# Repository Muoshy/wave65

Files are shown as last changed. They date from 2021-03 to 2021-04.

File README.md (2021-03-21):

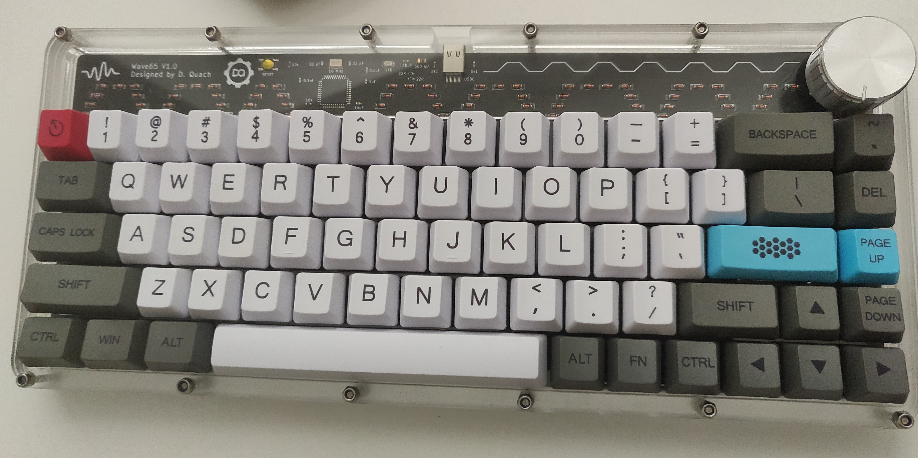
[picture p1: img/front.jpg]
top


# wave65
discipline65 inspired keyboard

  - QMK firmware
  - Acrylic sandwich case
  - Encoder support
  - VIA-configurable
  
## Schematic
Standard ATMega32u4 setup with Wurth/Amphenol USB-C connector
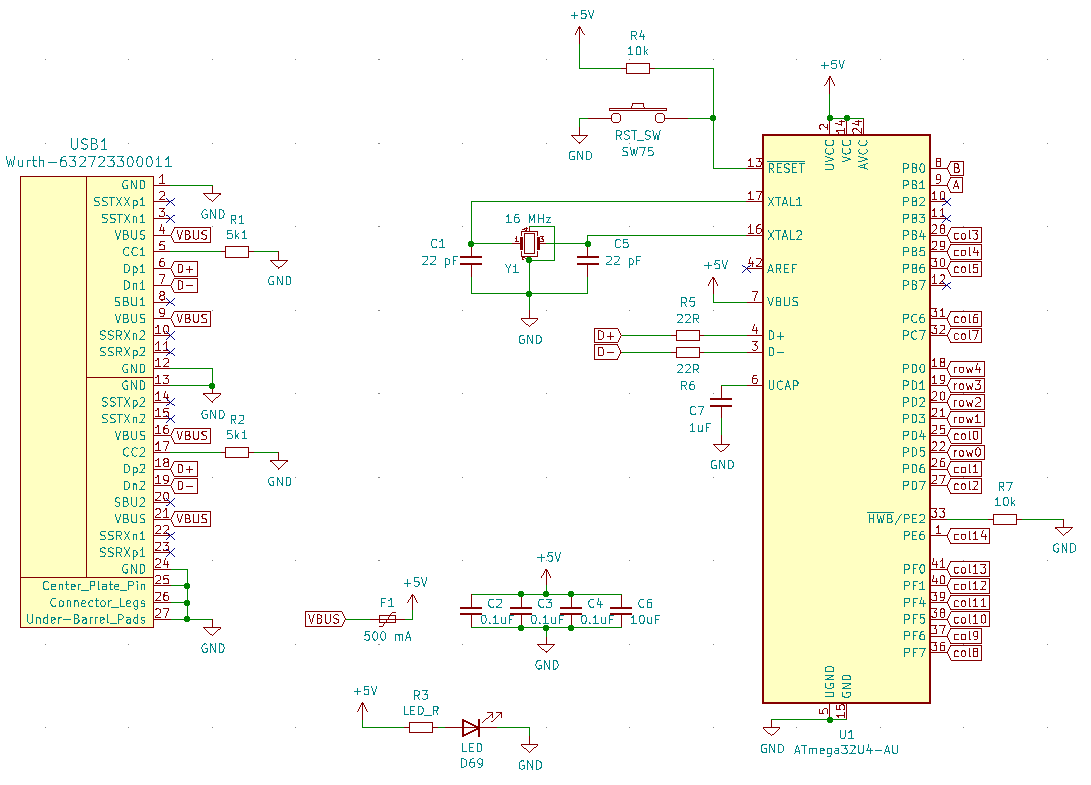
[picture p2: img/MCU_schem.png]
sch


## PCB
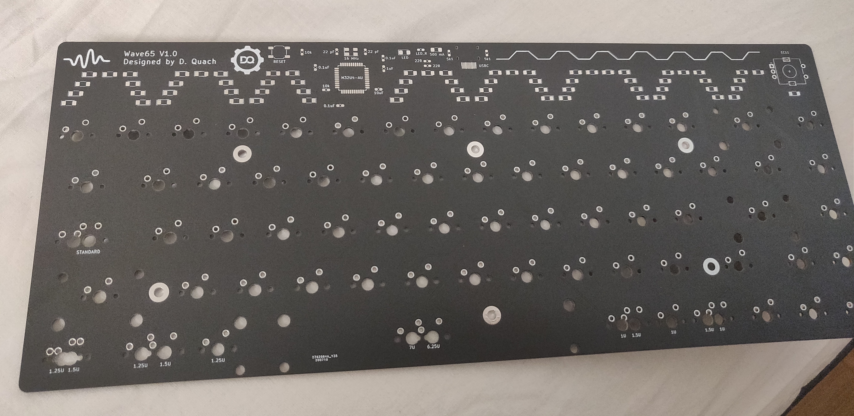
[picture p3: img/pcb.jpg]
pcb


## Case
WIP

## Software
Running on QMK firmware. Use QMK Toolbox to flash with provided HEX file.
Then use VIA configurator to configure keybinds.
For further customization (encoder keycodes), setup a QMK build environment and compile your own HEX files.

## Flashing
  - Download and open QMK Toolbox
  - Select HEX file
  - Choose ATMega32u4 as microcontroller
  - Push reset button on board and then press flash button in toolbox.

## Keybinds
  - Download and install VIA Configurator
  - Open VIA and go to File->Import Keymap
  - Select the keymap.json file
  - Plug in the keyboard

## BOM
WIP

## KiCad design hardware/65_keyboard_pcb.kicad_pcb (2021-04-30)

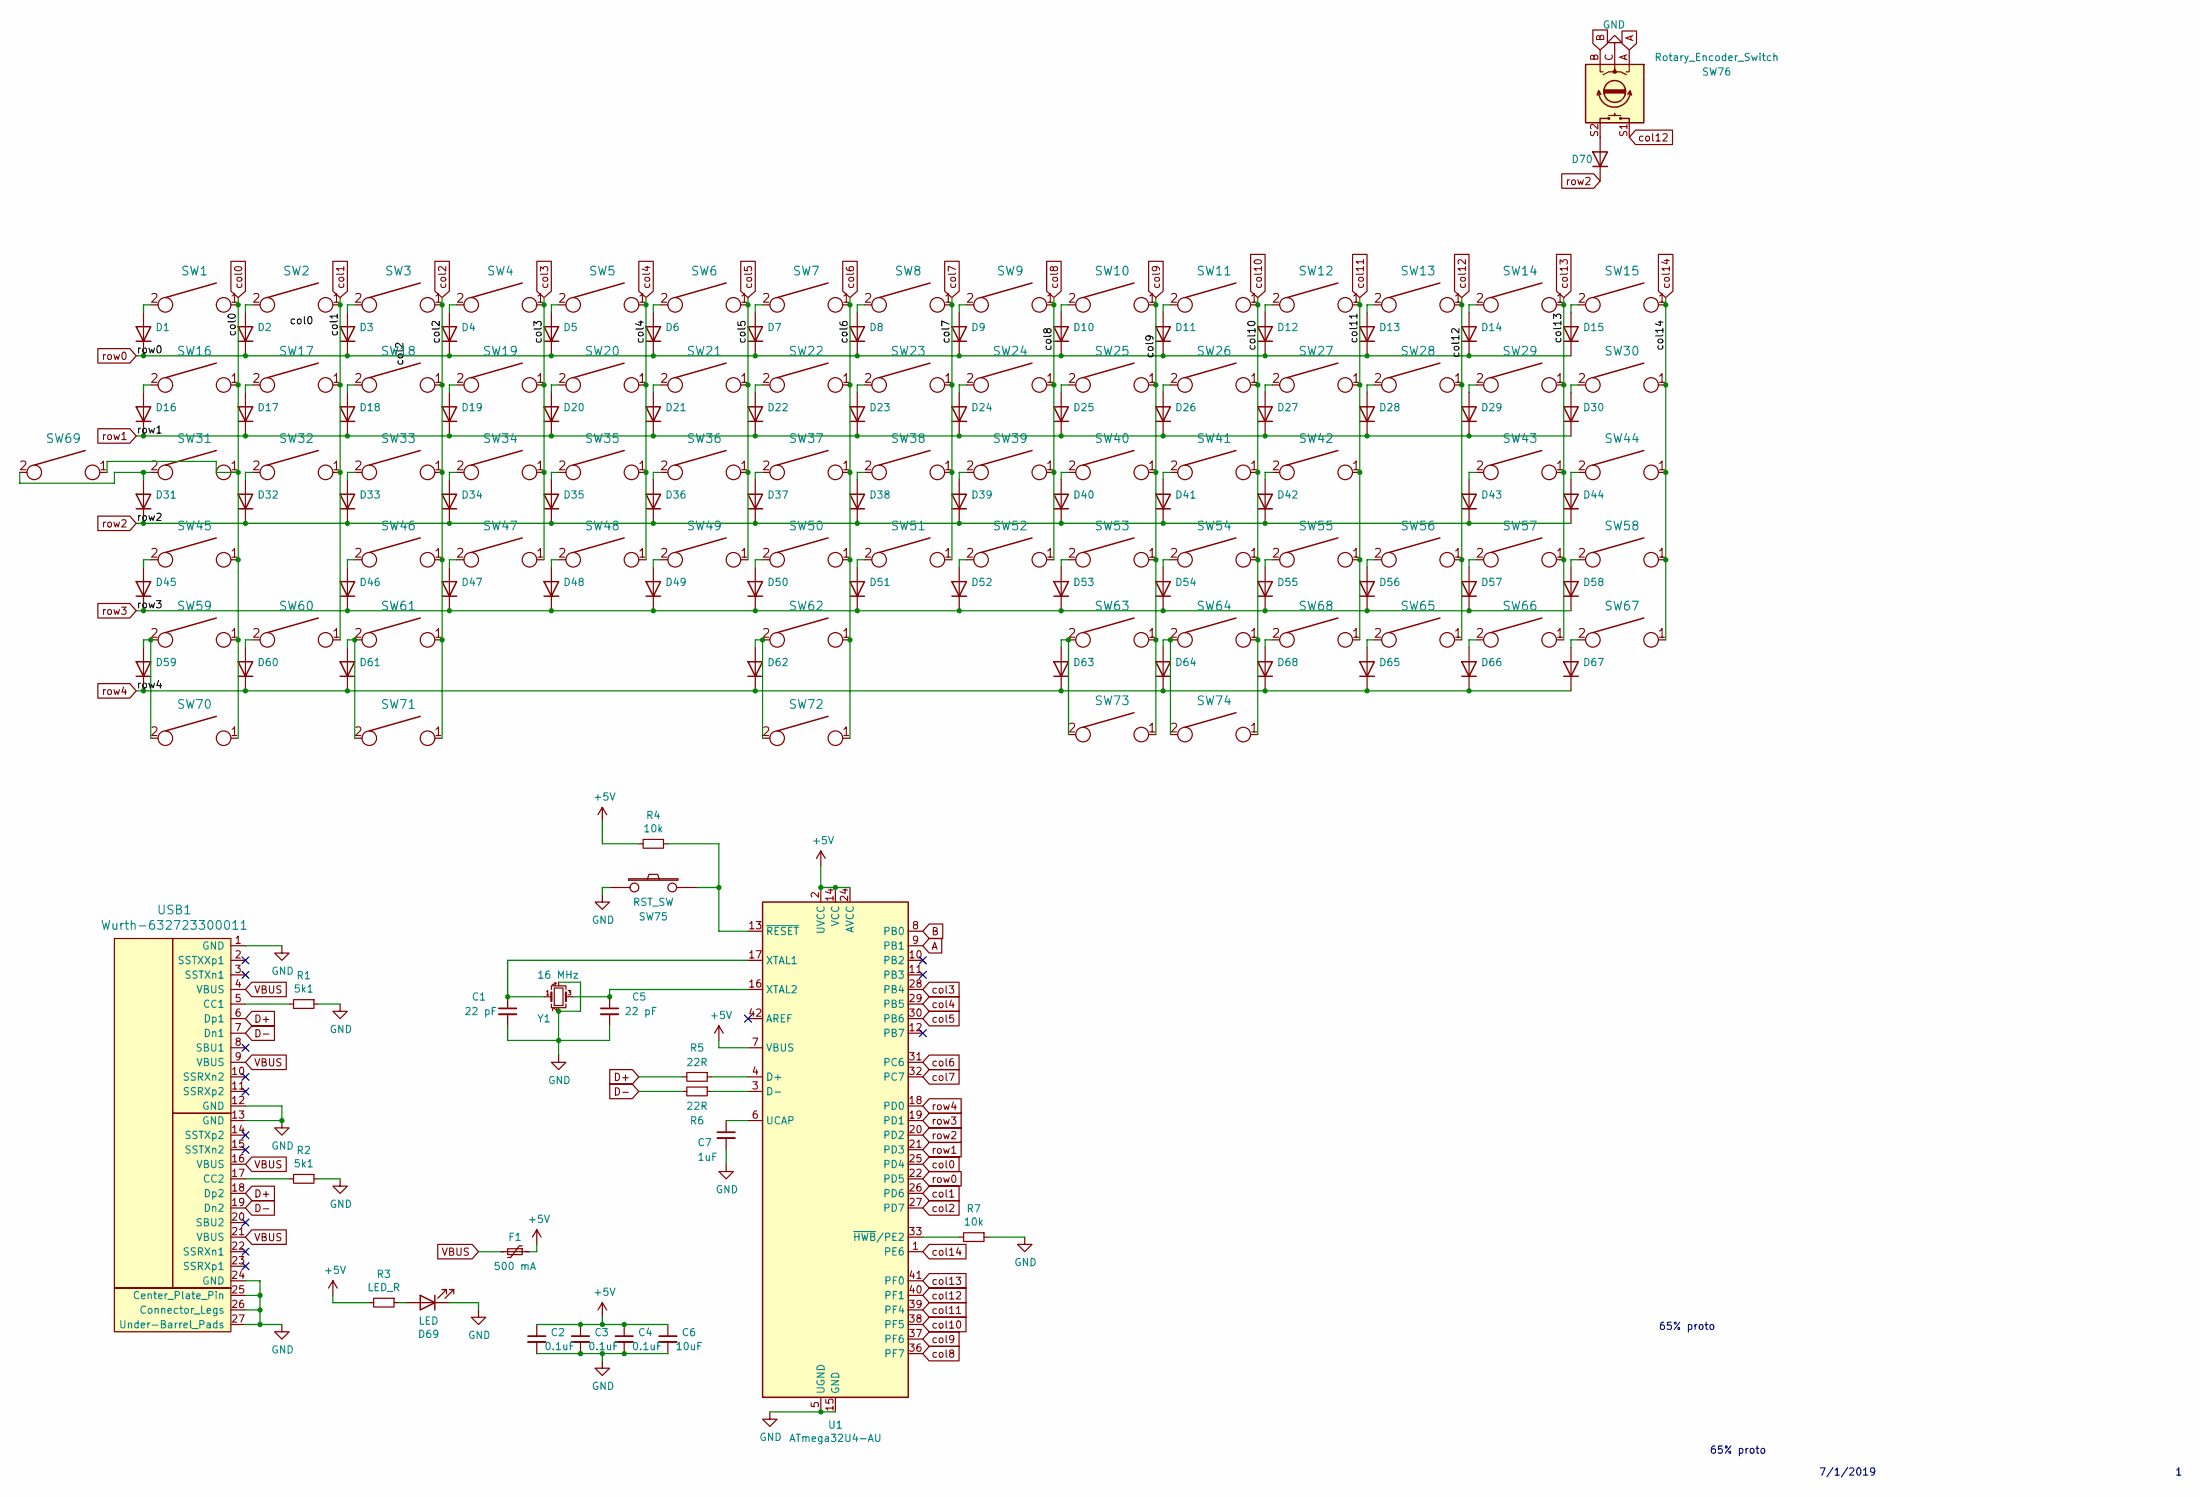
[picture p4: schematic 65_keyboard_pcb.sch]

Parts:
C1, C5: 22 pF; C_0603_1608Metric_Pad1.05x0.95mm_HandSolder
C2, C3, C4: 0.1uF; C_0603_1608Metric_Pad1.05x0.95mm_HandSolder
C6: 10uF; C_0603_1608Metric_Pad1.05x0.95mm_HandSolder
C7: 1uF; C_0603_1608Metric_Pad1.05x0.95mm_HandSolder
D1, D2, D3, D4, D5, D6, D7, D8, D9, D10, D11, D12, D13, D14, D15, D16, D17, D18, D19, D20, D21, D22, D23, D24, D25, D26, D27, D28, D29, D30, D31, D32, D33, D34, D35, D36, D37, D38, D39, D40, D41, D42, D43, D44, D45, D46, D47, D48, D49, D50, D51, D52, D53, D54, D55, D56, D57, D58, D59, D60, D61, D62, D63, D64, D65, D66, D67, D68, D70: D_MiniMELF
D69: LED; LED_1206_3216Metric_Pad1.42x1.75mm_HandSolder
F1: 500 mA; Fuse_1206_3216Metric_Pad1.42x1.75mm_HandSolder
R1, R2: 5k1; R_0603_1608Metric_Pad1.05x0.95mm_HandSolder
R3: LED_R; R_0603_1608Metric_Pad1.05x0.95mm_HandSolder
R4, R7: 10k; R_0603_1608Metric_Pad1.05x0.95mm_HandSolder
R5, R6: 22R; R_0603_1608Metric_Pad1.05x0.95mm_HandSolder
SW1, SW2, SW3, SW4, SW5, SW6, SW7, SW8, SW9, SW10, SW11, SW12, SW13, SW15, SW17, SW18, SW19, SW20, SW21, SW22, SW23, SW24, SW25, SW26, SW27, SW28, SW30, SW32, SW33, SW34, SW35, SW36, SW37, SW38, SW39, SW40, SW41, SW42, SW44, SW46, SW47, SW48, SW49, SW50, SW51, SW52, SW53, SW54, SW55, SW57, SW58, SW62, SW65, SW66, SW67, SW68, SW72: KEYSW; SW_Cherry_MX1A_1.00u_PCB-NOSCREEN
SW14: KEYSW; SW_Cherry_MX1A_2.00u_PCBNOSCREEN
SW16, SW29, SW70, SW71, SW73, SW74: KEYSW; SW_Cherry_MX1A_1.50u_PCBNOSCREEN
SW31, SW56: KEYSW; SW_Cherry_MX1A_1.75u_PCBNOSCREEN
SW43, SW45: KEYSW; SW_Cherry_MX1A_2.25u_PCBNOSCREEN
SW59, SW60, SW61, SW63, SW64, SW69: KEYSW; SW_Cherry_MX1A_1.25u_PCBNOSCREEN
SW75: RST_SW; SW_PTS525SM15SMTR2LFS
SW76: Rotary_Encoder_Switch; RotaryEncoder_Alps_EC11E-Switch_Vertical_H20mm
U1: ATmega32U4-AU; TQFP-44_10x10mm_P0.8mm
USB1: Wurth-632723300011; Wurth-632723300011-HandSoldering
Y1: 16 MHz; Crystal_SMD_5032-4Pin_5.0x3.2mm

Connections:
+5V: C2.1, C3.1, C4.1, C6.1, F1.1, R3.2, R4.2, U1.2 (UVCC), U1.7 (VBUS), U1.14 (VCC), U1.24 (AVCC), U1.34 (VCC), U1.44 (AVCC)
A: SW76.A, U1.9 (PB1)
B: SW76.B, U1.8 (PB0)
D+: R5.2, USB1.6 (Dp1), USB1.18 (Dp2); also elsewhere on the board
D-: R6.2, USB1.7 (Dn1), USB1.19 (Dn2); also elsewhere on the board
GND: C1.2, C2.2, C3.2, C4.2, C5.2, C6.2, C7.2, D69.1 (K), R1.1, R2.1, R7.1, SW75.1, SW76.C, U1.5 (UGND), U1.15 (GND), U1.23 (GND), U1.35 (GND), U1.43 (GND), USB1.1 (GND), USB1.12 (GND), USB1.13 (GND), USB1.24 (GND), USB1.25 (Center_Plate_Pin), USB1.26 (Connector_Legs), USB1.27 (Under-Barrel_Pads), Y1.2, Y1.4; also elsewhere on the board
unnamed: C1.1, U1.17 (XTAL1), Y1.1
unnamed: C5.1, U1.16 (XTAL2), Y1.3
unnamed: C7.1, U1.6 (UCAP)
unnamed: D1.2 (A), SW1.2
unnamed: D2.2 (A), SW2.2
unnamed: D3.2 (A), SW3.2
unnamed: D4.2 (A), SW4.2
unnamed: D5.2 (A), SW5.2
unnamed: D6.2 (A), SW6.2
unnamed: D7.2 (A), SW7.2
unnamed: D8.2 (A), SW8.2
unnamed: D9.2 (A), SW9.2
unnamed: D10.2 (A), SW10.2
unnamed: D11.2 (A), SW11.2
unnamed: D12.2 (A), SW12.2
unnamed: D13.2 (A), SW13.2
unnamed: D14.2 (A), SW14.2
unnamed: D15.2 (A), SW15.2
unnamed: D16.2 (A), SW16.2
unnamed: D17.2 (A), SW17.2
unnamed: D18.2 (A), SW18.2
unnamed: D19.2 (A), SW19.2
unnamed: D20.2 (A), SW20.2
unnamed: D21.2 (A), SW21.2
unnamed: D22.2 (A), SW22.2
unnamed: D23.2 (A), SW23.2
unnamed: D24.2 (A), SW24.2
unnamed: D25.2 (A), SW25.2
unnamed: D26.2 (A), SW26.2
unnamed: D27.2 (A), SW27.2
unnamed: D28.2 (A), SW28.2
unnamed: D29.2 (A), SW29.2
unnamed: D30.2 (A), SW30.2
unnamed: D31.2 (A), SW31.2, SW69.2
unnamed: D32.2 (A), SW32.2
unnamed: D33.2 (A), SW33.2
unnamed: D34.2 (A), SW34.2
unnamed: D35.2 (A), SW35.2
unnamed: D36.2 (A), SW36.2
unnamed: D37.2 (A), SW37.2
unnamed: D38.2 (A), SW38.2
unnamed: D39.2 (A), SW39.2
unnamed: D40.2 (A), SW40.2
unnamed: D41.2 (A), SW41.2
unnamed: D42.2 (A), SW42.2
unnamed: D43.2 (A), SW43.2
unnamed: D44.2 (A), SW44.2
unnamed: D45.2 (A), SW45.2
unnamed: D46.2 (A), SW46.2
unnamed: D47.2 (A), SW47.2
unnamed: D48.2 (A), SW48.2
unnamed: D49.2 (A), SW49.2
unnamed: D50.2 (A), SW50.2
unnamed: D51.2 (A), SW51.2
unnamed: D52.2 (A), SW52.2
unnamed: D53.2 (A), SW53.2
unnamed: D54.2 (A), SW54.2
unnamed: D55.2 (A), SW55.2
unnamed: D56.2 (A), SW56.2
unnamed: D57.2 (A), SW57.2
unnamed: D58.2 (A), SW58.2
unnamed: D59.2 (A), SW59.2, SW70.2
unnamed: D60.2 (A), SW60.2
unnamed: D61.2 (A), SW61.2, SW71.2
unnamed: D62.2 (A), SW62.2, SW72.2
unnamed: D63.2 (A), SW63.2, SW73.2
unnamed: D64.2 (A), SW64.2, SW74.2
unnamed: D65.2 (A), SW65.2
unnamed: D66.2 (A), SW66.2
unnamed: D67.2 (A), SW67.2
unnamed: D68.2 (A), SW68.2
unnamed: D69.2 (A), R3.1
unnamed: D70.2 (A), SW76.S2
unnamed 79: R1.2, USB1.5 (CC1); also elsewhere on the board
unnamed 80: R2.2, USB1.17 (CC2); also elsewhere on the board
unnamed: R4.1, SW75.2, U1.13 (~RESET)
unnamed: R5.1, U1.4 (D+)
unnamed: R6.1, U1.3 (D-)
unnamed: R7.2, U1.33 (~HWB~/PE2)
VBUS: F1.2, USB1.4 (VBUS), USB1.9 (VBUS), USB1.16 (VBUS), USB1.21 (VBUS); also elsewhere on the board
col0: SW1.1, SW16.1, SW31.1, SW45.1, SW59.1, SW69.1, SW70.1, U1.25 (PD4)
col1: SW2.1, SW17.1, SW32.1, SW60.1, U1.26 (PD6)
col2: SW3.1, SW18.1, SW33.1, SW46.1, SW61.1, SW71.1, U1.27 (PD7)
col3: SW4.1, SW19.1, SW34.1, SW47.1, U1.28 (PB4)
col4: SW5.1, SW20.1, SW35.1, SW48.1, U1.29 (PB5)
col5: SW6.1, SW21.1, SW36.1, SW49.1, U1.30 (PB6)
col6: SW7.1, SW22.1, SW37.1, SW50.1, SW62.1, SW72.1, U1.31 (PC6)
col7: SW8.1, SW23.1, SW38.1, SW51.1, U1.32 (PC7)
col8: SW9.1, SW24.1, SW39.1, SW52.1, U1.36 (PF7)
col9: SW10.1, SW25.1, SW40.1, SW53.1, SW63.1, SW73.1, U1.37 (PF6)
col10: SW11.1, SW26.1, SW41.1, SW54.1, SW64.1, SW74.1, U1.38 (PF5)
col11: SW12.1, SW27.1, SW42.1, SW55.1, SW68.1, U1.39 (PF4)
col12: SW13.1, SW28.1, SW56.1, SW65.1, SW76.S1, U1.40 (PF1)
col13: SW14.1, SW29.1, SW43.1, SW57.1, SW66.1, U1.41 (PF0)
col14: SW15.1, SW30.1, SW44.1, SW58.1, SW67.1, U1.1 (PE6)
row0: D1.1 (K), D2.1 (K), D3.1 (K), D4.1 (K), D5.1 (K), D6.1 (K), D7.1 (K), D8.1 (K), D9.1 (K), D10.1 (K), D11.1 (K), D12.1 (K), D13.1 (K), D14.1 (K), D15.1 (K), U1.22 (PD5)
row1: D16.1 (K), D17.1 (K), D18.1 (K), D19.1 (K), D20.1 (K), D21.1 (K), D22.1 (K), D23.1 (K), D24.1 (K), D25.1 (K), D26.1 (K), D27.1 (K), D28.1 (K), D29.1 (K), D30.1 (K), U1.21 (PD3)
row2: D31.1 (K), D32.1 (K), D33.1 (K), D34.1 (K), D35.1 (K), D36.1 (K), D37.1 (K), D38.1 (K), D39.1 (K), D40.1 (K), D41.1 (K), D42.1 (K), D43.1 (K), D44.1 (K), D70.1 (K), U1.20 (PD2)
row3: D45.1 (K), D46.1 (K), D47.1 (K), D48.1 (K), D49.1 (K), D50.1 (K), D51.1 (K), D52.1 (K), D53.1 (K), D54.1 (K), D55.1 (K), D56.1 (K), D57.1 (K), D58.1 (K), U1.19 (PD1)
row4: D59.1 (K), D60.1 (K), D61.1 (K), D62.1 (K), D63.1 (K), D64.1 (K), D65.1 (K), D66.1 (K), D67.1 (K), D68.1 (K), U1.18 (PD0)

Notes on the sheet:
65% proto
7/1/2019

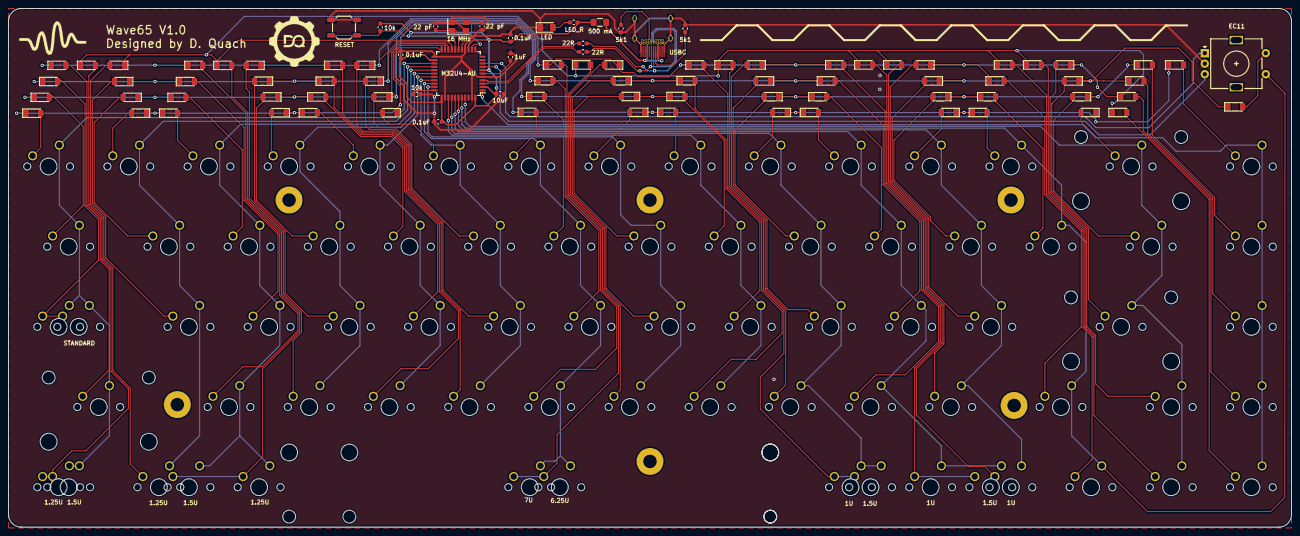
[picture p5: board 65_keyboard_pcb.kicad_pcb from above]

Board: 2 copper layers, 304.8 x 123.2 mm, 165 parts (0 on the bottom side), 106 nets.

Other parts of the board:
ST62: 7U; MX-7U-Stabilizer
USBC: Wurth-632723300011; Wurth-632723300011-HandSoldering

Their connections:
D+: USBC.6, USBC.18; also elsewhere on the board
D-: USBC.7, USBC.19; also elsewhere on the board
GND: USBC.1, USBC.12, USBC.13, USBC.24, USBC.25, USBC.26; also elsewhere on the board
unnamed 79: USBC.5; also elsewhere on the board
unnamed 80: USBC.17; also elsewhere on the board
VBUS: USBC.4, USBC.9, USBC.16, USBC.21; also elsewhere on the board
